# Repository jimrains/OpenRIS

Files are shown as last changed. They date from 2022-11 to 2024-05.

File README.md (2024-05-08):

# OpenRIS



Reconfigurable Intelligent Surface project for the WiDeS Group at USC / CSI Group at University of Glasgow. Please direct enquiries to james.rains@essex.ac.uk. 

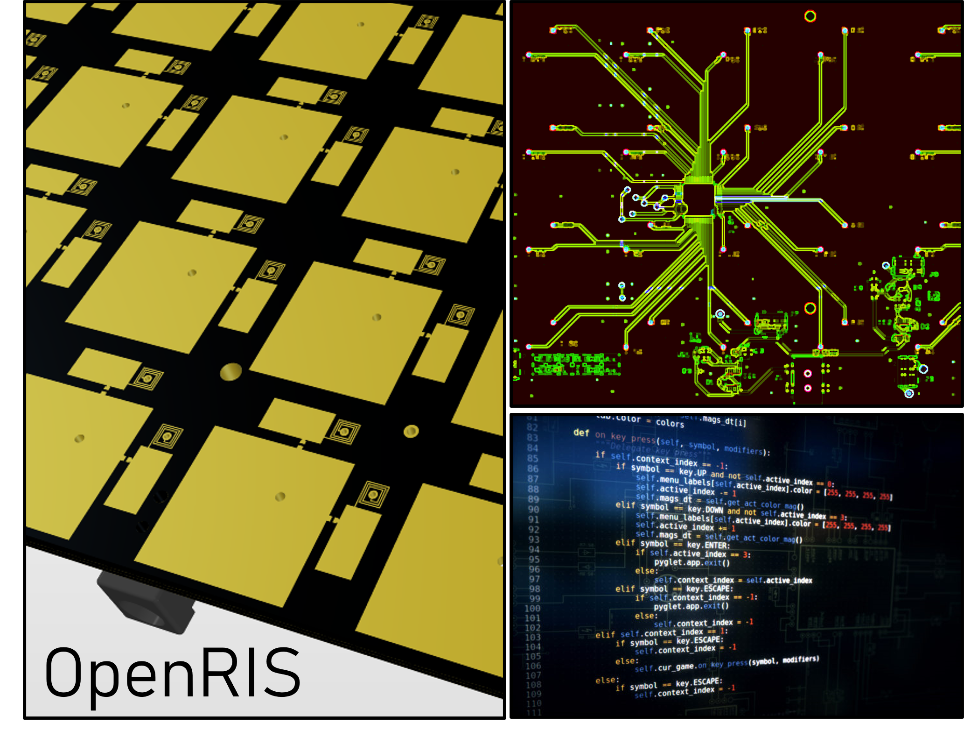
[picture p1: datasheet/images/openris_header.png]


# Documentation

- [Datasheet](https://github.com/jimrains/USCRIS/tree/main/datasheet) - general performance information
- [Control interface](https://github.com/jimrains/USCRIS/tree/main/control) - programming information
- [Hardware](https://github.com/jimrains/USCRIS/tree/main/hardware) - details of the digital hardware
- [Publications](https://github.com/jimrains/USCRIS/tree/main/publications) - papers on and involving the OpenRIS prototype
- [Measurements](https://github.com/jimrains/USCRIS/tree/main/measurements) - data on far-field pattern measurements and channel sounding

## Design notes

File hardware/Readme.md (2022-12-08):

# Hardware

This directory contains information regarding the RIS digital hardware. For information regarding the design of the metasurface, see [this paper](https://github.com/jimrains/USCRIS/blob/main/publications/1_bit_DP_EuCAP_2023_Conference-5.pdf).

## Metasurface

## Control circuit

The below diagram shows the digital circuit side of a RIS tile. Each tile consists of 16 high voltage shift registers, each with 32 digital outputs which can take on voltage levels of 0 and V2 volts for logic low and logic high, respectively. These shift registers are addressed by a Raspberry Pi 3B via a logic level shifter. A power distribution circuit transforms the voltage at the input jack into two manually tunable voltage levels.

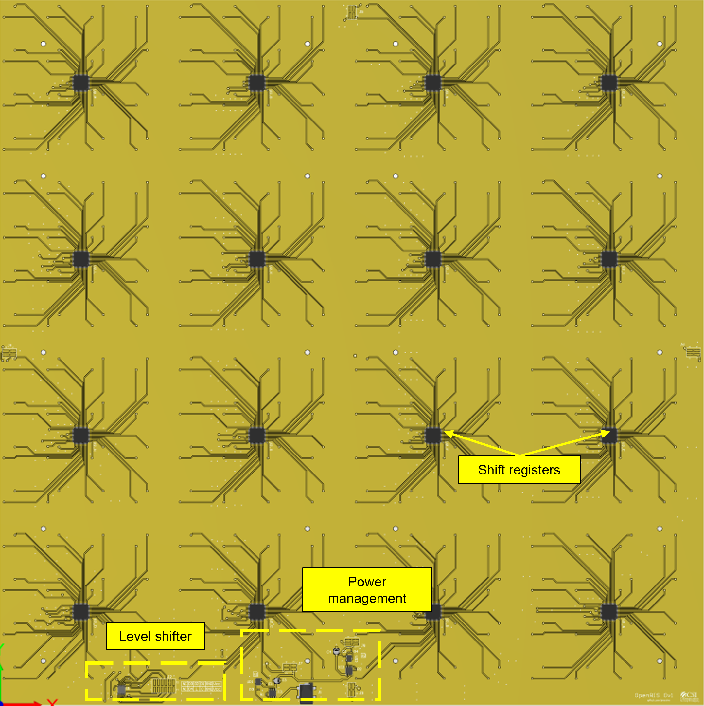
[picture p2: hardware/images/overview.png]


## Subcircuits

### Shift registers

There are a total of 512 individually controllable varactor diodes per tile, served by a network of shift registers. The control circuitry is centred around HV5308 shift registers. These are cascaded in groups of 4. Each shift register contains 32 digital outputs with logic levels 0 and V2 volts. A single shift register supports the 2 polarisations of 16 unit cells such that they may be individually addressed.

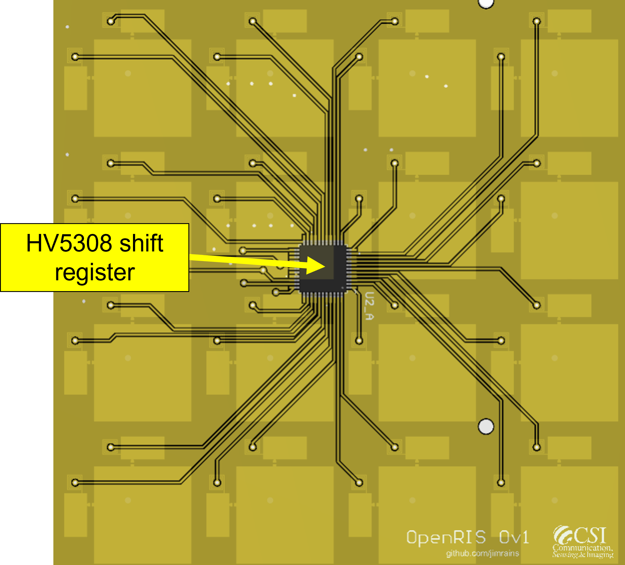
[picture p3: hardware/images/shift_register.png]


### Level shifter

To interface with the high voltage shift registers, the digital control signals from the Raspberry Pi need to be converted to a higher voltage. The Raspberry Pi GPIO pins provide a logical low and high of 0 V and 3.3 V, respectively. The HV5308 ICs have a recommended operating voltage of 8 - 12 V. We use the CD4504 shift register ICs for this logic voltage level shifting. A logic high of 3.3 V is converted into the shift register logic voltage, V2.

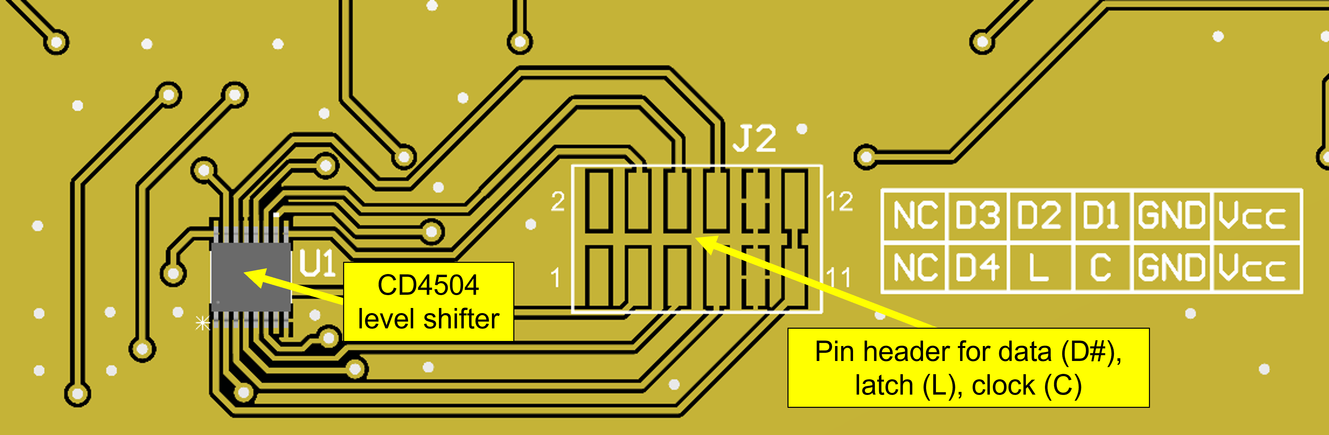
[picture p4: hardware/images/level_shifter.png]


The pinout for this can be found on the [datasheet](../datasheet) page and a print of the tile-side pinout can be seen in the above image.

### Power management

Voltage regulation is performed by two LN2954 ICs, providing V1 and V2. V1 is applied to the square patches of the RIS elements and V2 is used as the logic high level for the shift registers. These have been placed in series so that V2 is always greater than V1. This is to ensure that the varactor diodes are always reverse-biased.

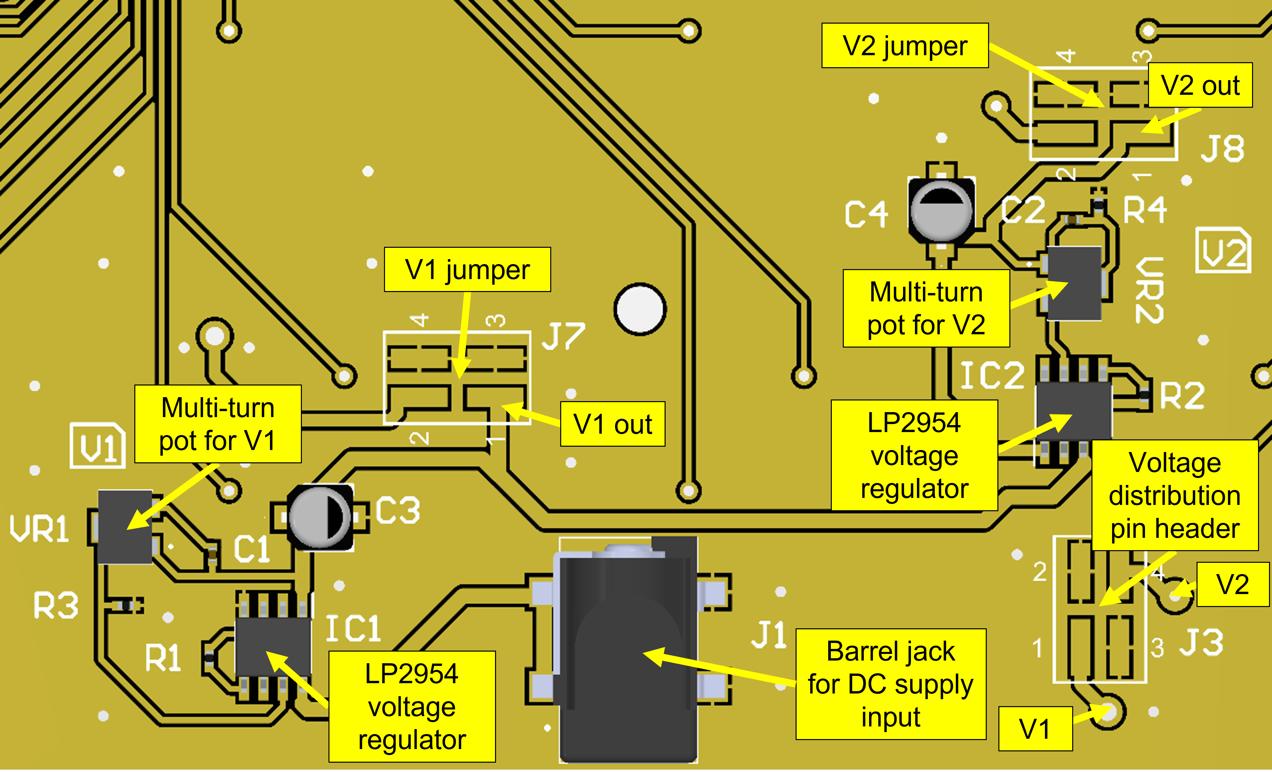
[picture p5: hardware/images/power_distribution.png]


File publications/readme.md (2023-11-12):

# Publications

We have published work on the initial design in EuCAP 2023 which can be found:
[Rains et al., Fully-Addressable Varactor-Based Reflecting Metasurface with Dual-Linear Polarisation for Low Power Reconfigurable Intelligent Surfaces, EuCAP 2023](https://ieeexplore.ieee.org/abstract/document/10133408)

Field trials in an outdoor urban macrocell were recently performed and the results will be published shortly. A draft of the paper can be found in this directory, titled RIS-Enhanced MIMO Channels in Urban Environments: Experimental Insights.

For similar work by the authors, see:
[Rains, Kazim, Tukmanov et al., High-Resolution Programmable Scattering for Wireless Coverage Enhancement: An Indoor Field Trial Campaign, IEEE Transactions on Antennas and Propagation, 2022](https://ieeexplore.ieee.org/abstract/document/9931620)

[Usman, Rains, Cui et al., Intelligent wireless walls for contactless in-home monitoring, Nature LSA, 2022](https://www.nature.com/articles/s41377-022-00906-5)

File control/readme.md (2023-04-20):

# Control

This directory contains all the information necessary to set up and interface with the RIS prototype. 

RIS configurations are sent over a WiFi link hosted on the Raspberry Pi 3B. A socket is established with MATLAB acting as the client, connecting to a server running on the Raspberry Pi. The server-side software is currently written in Python. Configurations sent via MATLAB are transformed into the correct format by the Python program on the Pi side. The Pi then sets the digital states of the GPIO pins to program the shift registers on the respective RIS tiles. 

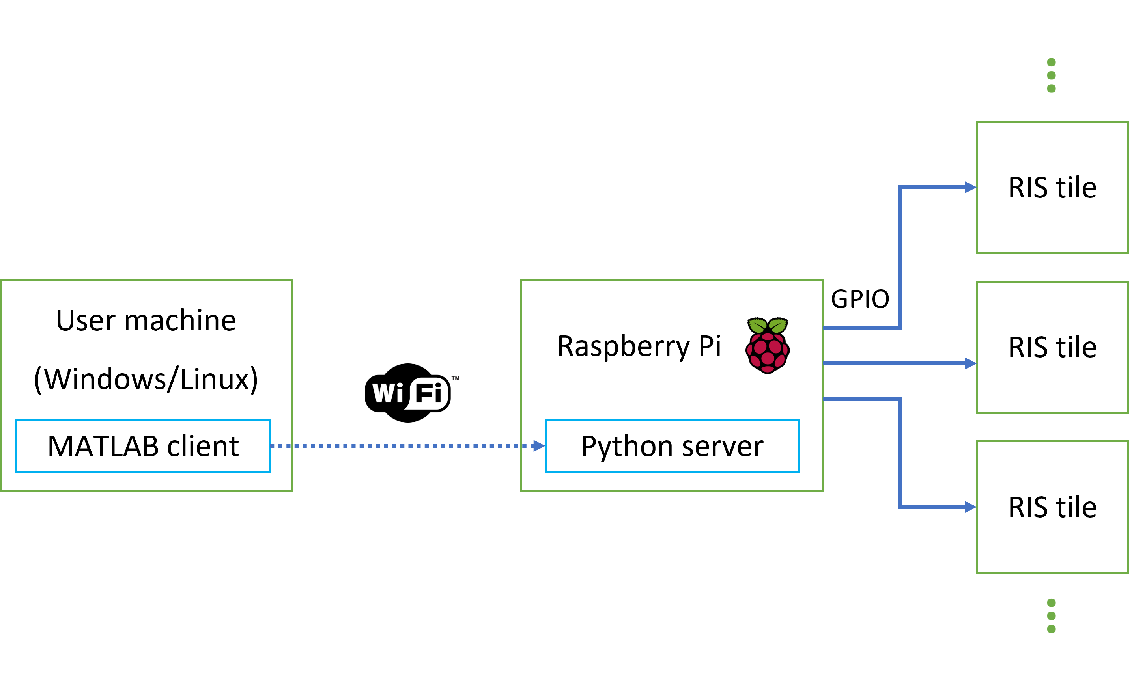
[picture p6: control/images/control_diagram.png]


## Ethernet Connection

It is possible to connect to the Raspberry Pi via an ethernet cable through a secure shell through the command:

**ssh pi@raspberrypi.local**

with the default password.

## WiFi Access Point

By default, the access point on the USC prototype is set up on boot, with an access point name **PiRS**. The password is the default and won't be posted here for obvious reasons (just ask James or others in the project). 

To set up an access point on the Raspberry Pi 3B from a fresh install, see the guide posted [here](https://learn.sparkfun.com/tutorials/setting-up-a-raspberry-pi-3-as-an-access-point/all). Note the static IP address you use in the __interfaces__ file.

As an alternative, you may set up a mobile hotspot on a PC and get the Pi to connect to you. To keep things simple, you may connect a monitor/keyboard/mouse to the Pi the first time you do this. 

## Socket Setup

The current procedure for setting up a socket for RIS control involves:

- Connect to the **PiRS** WiFi access point from the user machine
- Establish control of the Pi via SSH (i.e., via the command __ssh pi@192.168.4.1__). Use the default username and password.
- Run the program **python ~/control/socket-server-tiles.py**
- Note the port number **port_number** (this can be found in the **PORT** variable in the program)
- In MATLAB on the user machine, run the command **sock = tcpclient("192.168.4.1", port_number)** where **port_number** is an integer of the port number displayed when running the server

## MATLAB Interfacing

Configurations are sent over the socket in the form of a string of bits. Additionally, a tile number is sent so that the Pi knows which set of GPIO pins it should send the control signals over. 

## Pinouts

### Tile pinout

Each RIS tile requires 6 digital inputs alongside a DC voltage and a ground connection. The DC voltage should be the same level as the logic high. For the Raspberry Pi 3B, this will be 3.3 V. 

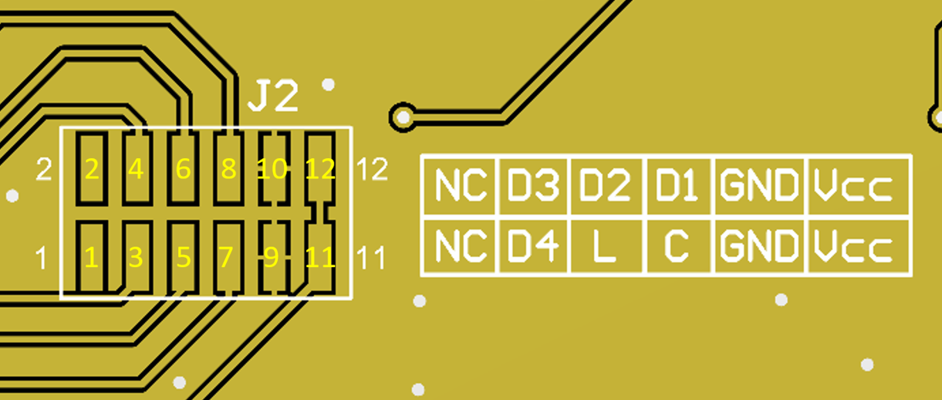
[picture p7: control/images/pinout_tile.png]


| Pin # | ID | Function | T1->Raspberry Pi | T2->Raspberry Pi |
|---|---|---|---|---|
| 1 | NC | Not connected | - | - |
| 2 | NC | Not connected | - | - |
| 3 | D4 | Data line 4 | 3->12 | 3->19 |
| 4 | D3 | Data line 3 | 4->10 | 4->18 |
| 5 | L | Latch (shifts out data to shift register outputs)  | 5->5 | 5->13 |
| 6 | D2 | Data line 2 | 6->8 | 6->16 |
| 7 | C | Clock (timing signal) | 7->3 | 7->11 |
| 8 | D1 | Data line 1 | 8->7 | 8->15 |
| 9 | GND  | DC ground | 9->6 | 9->14 |
| 10 | GND  | DC ground | - | - |
| 11 | Vcc  | DC voltage (3.3 V for Pi 3B) | 11->1 | 11->17 |
| 12 | Vcc  | DC voltage (3.3 V for Pi 3B) | - | - |

### Pi pinout



The pinout of the Raspberry Pi 3 will depend on the number of tiles that are utilised for a particular arrangement. This is governed by the **tile.h** file in this directory. The pin mapping for two tiles is shown in the two right-hand columns in the table above. The Pi GPIO pin numbers refer to the __board__ numbering scheme (i.e., the physical pin number). For more information on the Raspberry Pi GPIO interface, see [here](https://www.raspberrypi.com/documentation/computers/raspberry-pi.html#gpio-and-the-40-pin-header). 

## Pi Graphical User Interface

If for whatever reason you need to access the graphical user interface (GUI) of the Raspberry Pi, you can use a VNC viewer. One such program is RealVNC which can be found [here](https://www.realvnc.com/en/connect/download/vnc/). Follow the first two instructions in the **Socket Setup** section above, then:

- In the secure shell, run the command **vncserver**. Note down the IP address and the number following the colon.
- Open VNC Viewer or an equivalent program. Use the VNC server address **192.168.4.1:#** where **#** is the number obtained in the previous step (typically defaults to 1 if no other session is open).
- Enter the username and password of the Pi. This is set to default.

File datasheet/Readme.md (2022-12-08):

# Datasheet

This directory contains information on the device performance

## Overview of Operating Principles

A typical RIS deployment is shown in the image below. A receiver located within the user equipment (UE) is served by the base station (BS) via the reconfigurable intelligent surface (RIS), circumventing the highly-attenuating direct path between the BS and the UE.

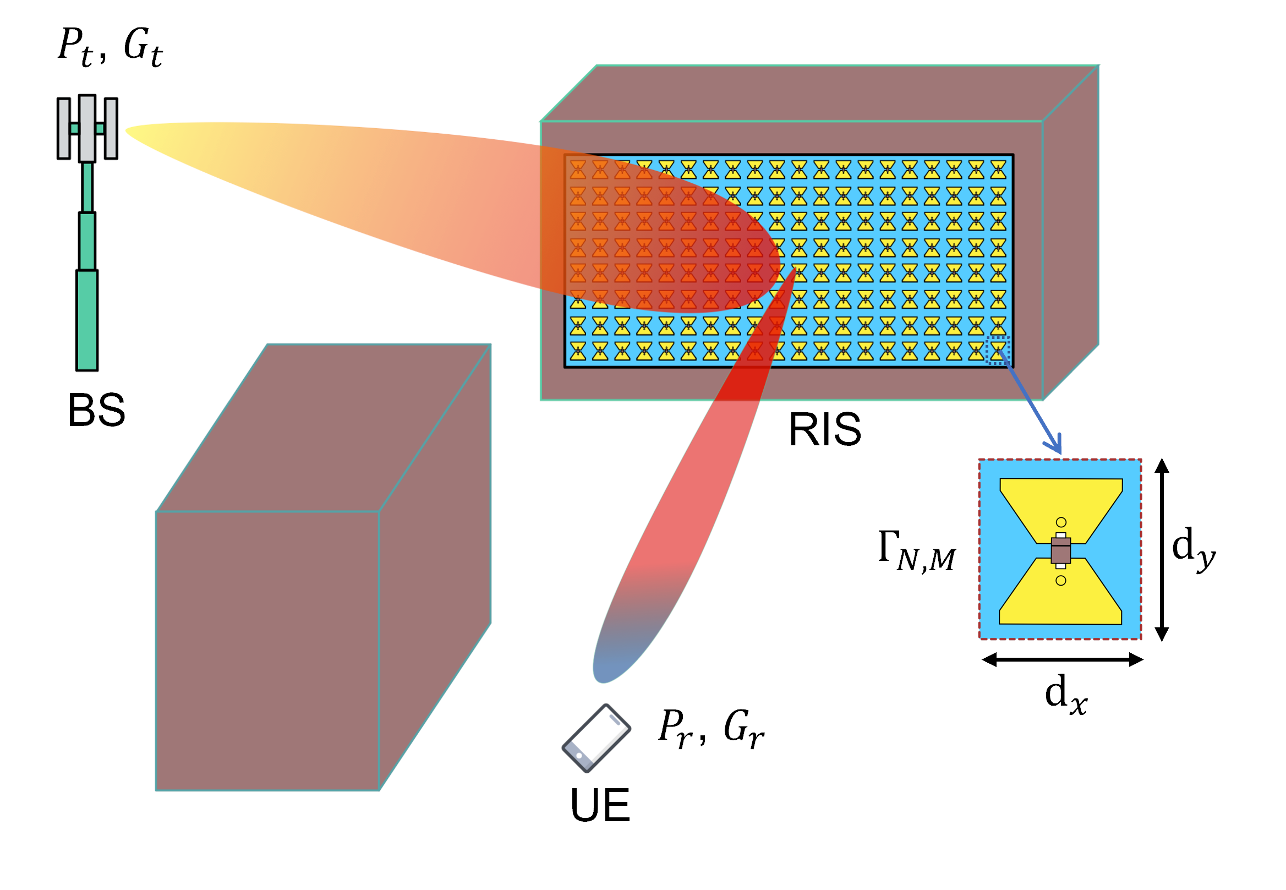
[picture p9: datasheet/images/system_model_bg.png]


If we consider a geometrical optics approximation, the below equation can be used to approximate the power $P_r$, received at an antenna with gain $G_r$, originating from reradiation from a RIS consisting of an arrangement of $MN$ elements. Each element is considered to have lateral dimensions $d_x$ and $d_y$ referring to the x and y axes, respectively. $\lambda$ is the wavelength at the frequency of interest. Taking the origin of the coordinate system at the center of the RIS, $r_{n,m}^t$ and $r_{n,m}^r$ are the distances between the transmitter and element (n,m) and the receiver and element (n,m), respectively. Any path between the transmitter and receiver is assumed to be neglible (thereby warranting the deployment of the RIS to mitigate this). The radiation patterns in reception and transmission are factored into the received power formulation through $F_{n,m}^{combine}$. 

$$ P_r = P_t\frac{G_tG_rd_xd_y\lambda^2}{64\pi^3}|\sum_{m=1-\frac{M}{2}}^{M/2}\sum_{n=1-\frac{N}{2}}^{N/2}\frac{\sqrt{F_{n,m}^{combine}}\ \Gamma_{n,m}}{r_{n,m}^tr_{n,m}^r}e^{(-j\frac{2\pi}{\lambda}(r_{n,m}^t+r_{n,m}^r))}|^2 $$

For a fixed RIS position, the controllability of the wireless channel is achieved through the tunability of $\Gamma_{n,m}$. For a given element geometry, $\Gamma_{n,m}$ determines the change in the phase and magnitude of an incident local electric field - this is observed on the re-radiated local electric field. As governed by the Huygen-Fresnel principle, we can craft the localised re-radiated electric field components such that they add constructively in a dominant direction, form a split beam, or any number of application-dependent forms. Elements are tuned by varying the reactance of the grid impedance associated with a given element. In the prototype in this archive, we have employed varactor diodes to provide this tunable impedance. The digital nature of the control circuitry limits us to 2 tuning states per polarisation per unit cell element. This does not pose a significant limitation on the beamforming performance of these devices.

### Examples

## Local Reflection Coefficients

To synthesise a desired RIS re-radiation response, we set the reflection coefficients $Γ_{n,m}$ associated with each unit cell. The RIS consists of many constituent elements, each of which can be tuned between 2 reflection coefficient values on each polarisation. This 2-state response is often referred to as a 1-bit response. The device provides a 1-bit reflection response at both linear polarisations. This 1-bit response needs to be tuned to the centre operating frequency. We can approximate what the local reflection coefficient for a given unit cell: 

- By placing the sample unit cell within a waveguide and measuring the S11, subject to some caveats (see [here](https://ieeexplore.ieee.org/abstract/document/5067833)), or
- By measuring the reflection response of a metasurface consisting of similar unit cell elements, each with the same bias conditions

We have opted for the second approach here since it requires no more equipment than that required for ascertaining the radiation patterns.

For information on usage of this local reflection coefficient data, skip to [here](https://github.com/jimrains/USCRIS/edit/main/datasheet/Readme.md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).

### Reflection coefficient measurement setup

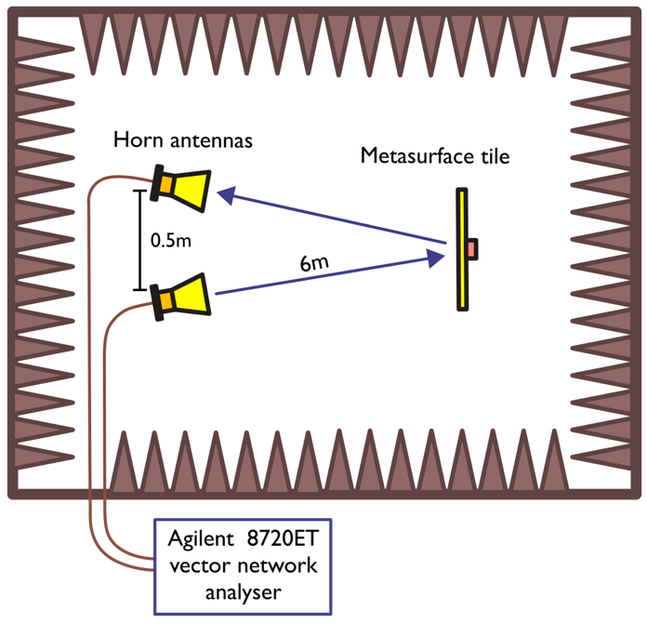
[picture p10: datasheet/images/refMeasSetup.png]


The two horn antennas, directed at the center of a single RIS tile, are positioned in the far-field of the sample. This distance should be approximately $r = 2D^2/\lambda$ where D is the lateral dimension and $\lambda$ is the shortest wavelength of interest. The antennas are spaced 0.5 m apart to avoid mutual coupling between them. The tile will reflect most of the incident power in the specular direction and this is what we exploit to ascertain the reflection coefficients. We assume that local reflection coefficients - that is, the complex coefficient determining the nature of the local electric field that is re-radiated from a given element on the surface - can be approximated by the global reflection behaviour of the surface. These reflection coefficients can be varied by changing the reverse-bias voltage of the varactor diodes in each unit cell. It is necessary to extract these values globally as it is difficult to measure the reflection response of any single unit cell.

### Calibration

In order to remove the contributions of the cables, horn antennas, and path loss from S21 response in the measurements, we first normalise to the reflection response of a homogenous metal plate. A copper plate is placed in contact with the tile face and the S21 is normalised. This results in the reference case of a "perfect" reflector. The reflection coefficients are then extracted by removing the copper plate and ascertaining the magnitude and phase responses for the varactor reverse bias voltage levels of interest.

### Local reflection response

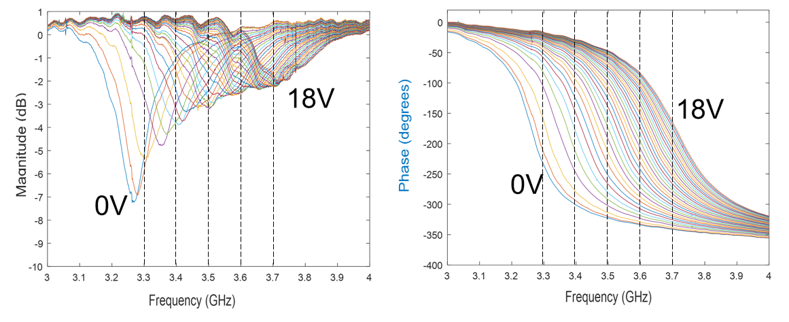
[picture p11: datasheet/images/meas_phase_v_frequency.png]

Γ magnitude and phase versus frequency

<br><br>

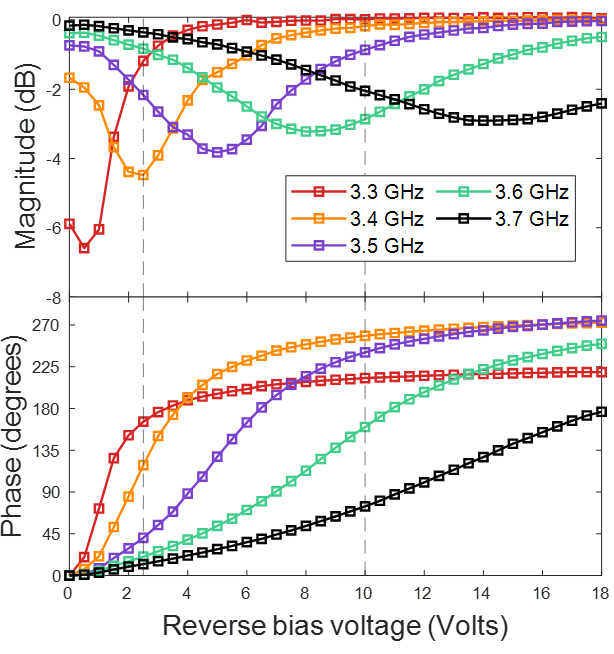
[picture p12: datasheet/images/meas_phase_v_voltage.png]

Γ magnitude and phase versus reverse-bias voltage

### Local reflection coefficients: how to use this data

The raw data for the local reflection responses is available in the measurements folder. 

## Radiation Patterns

For the **experiment setup** for extraction of the far-field patterns of a single tile, see [here](../measurements). Far-field to far-field radiation patterns have been extracted for 4 transmitter positions with incident angles, relative to broadside, of 0, 15, 30, and 45 degrees. Below is a representative example. The remaining curves and data can be found in the [measurements](../measurements) directory. The [numerical approximations]() are shown in blue, whilst the measured data points are displayed in red.

The measurement setup is depicted below and details can be found [here](../measurements).

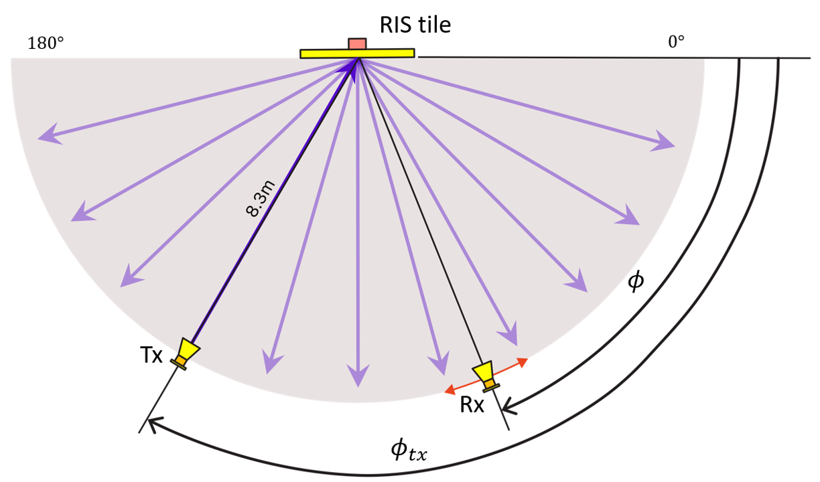
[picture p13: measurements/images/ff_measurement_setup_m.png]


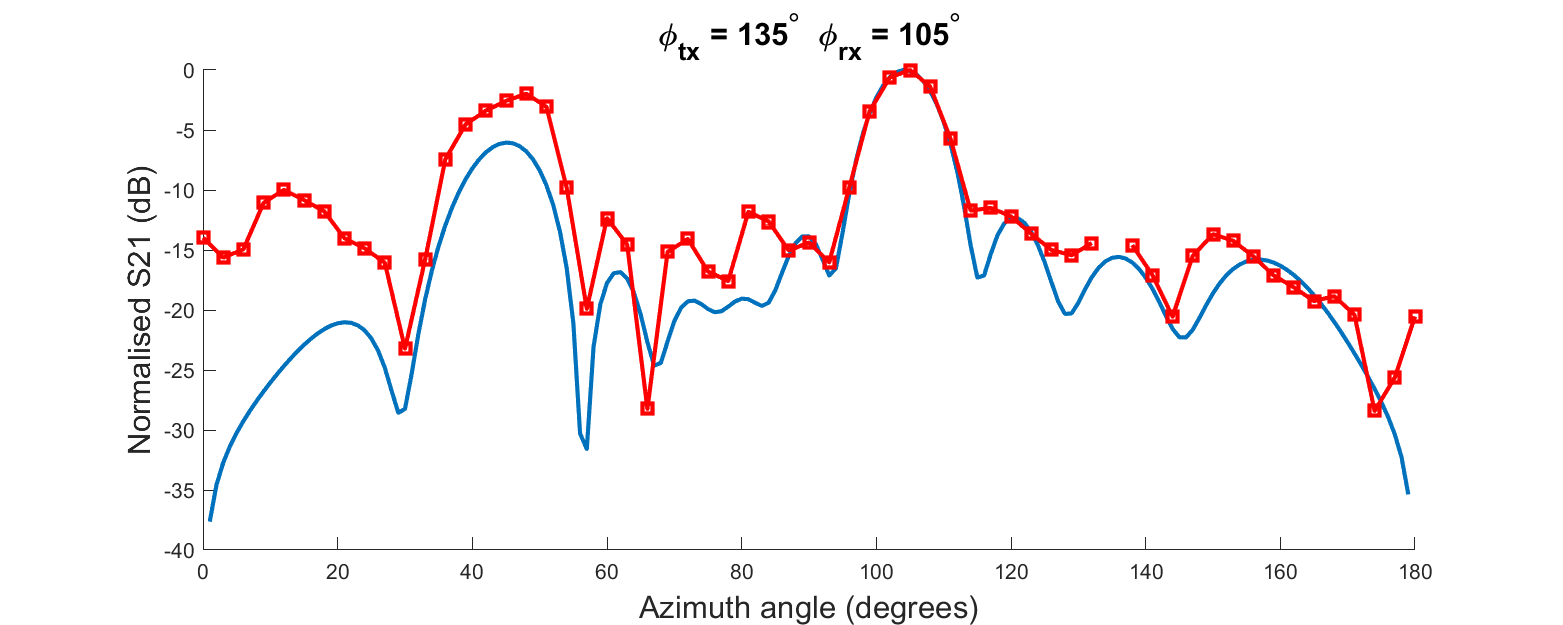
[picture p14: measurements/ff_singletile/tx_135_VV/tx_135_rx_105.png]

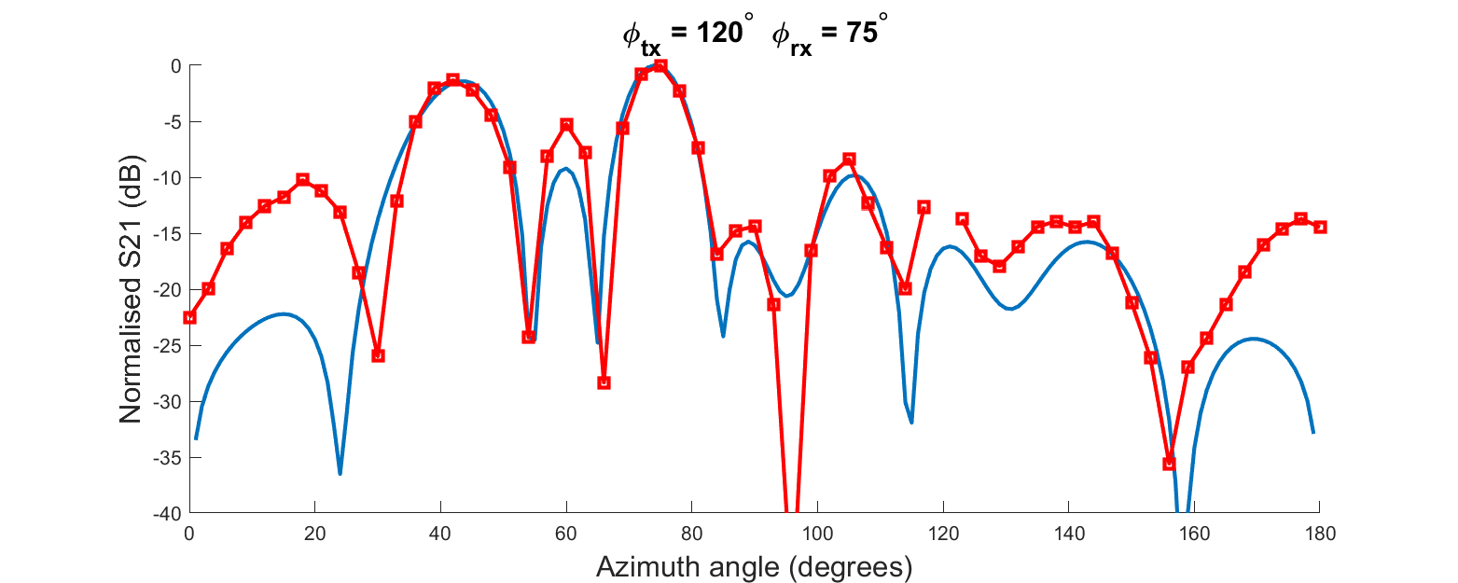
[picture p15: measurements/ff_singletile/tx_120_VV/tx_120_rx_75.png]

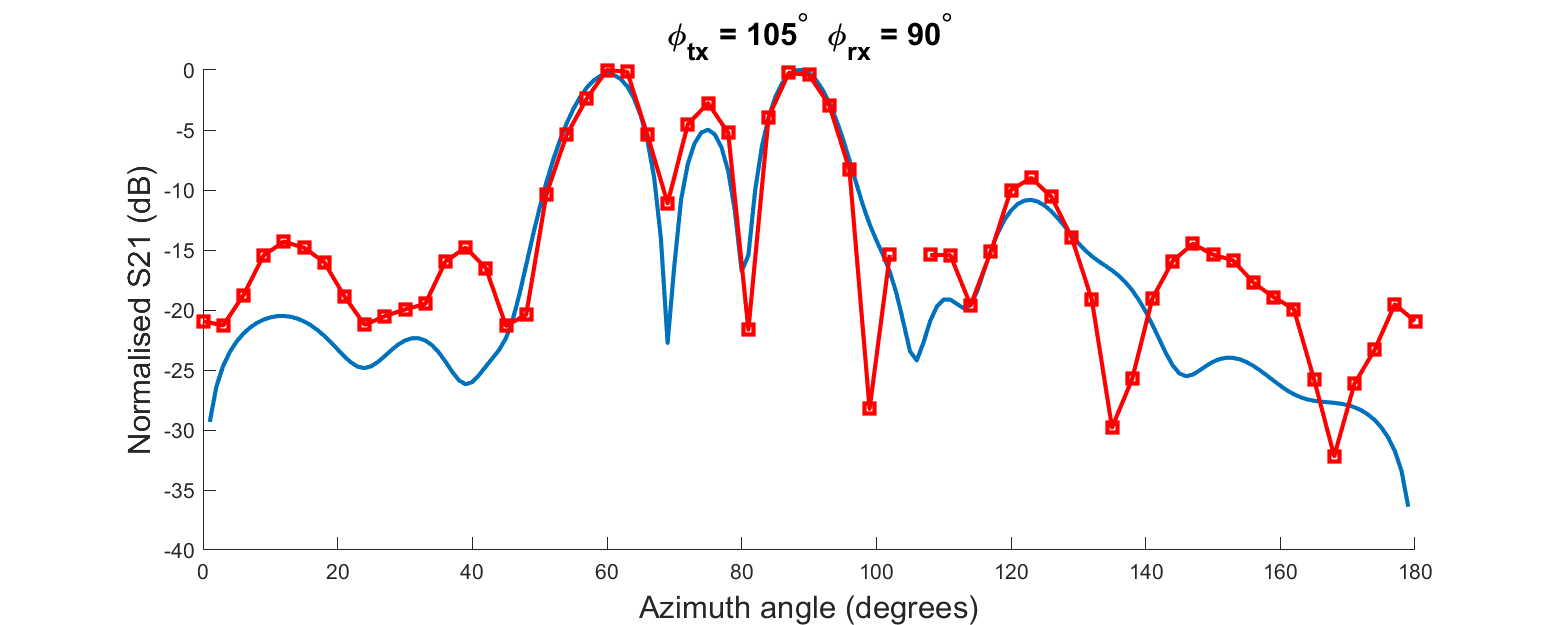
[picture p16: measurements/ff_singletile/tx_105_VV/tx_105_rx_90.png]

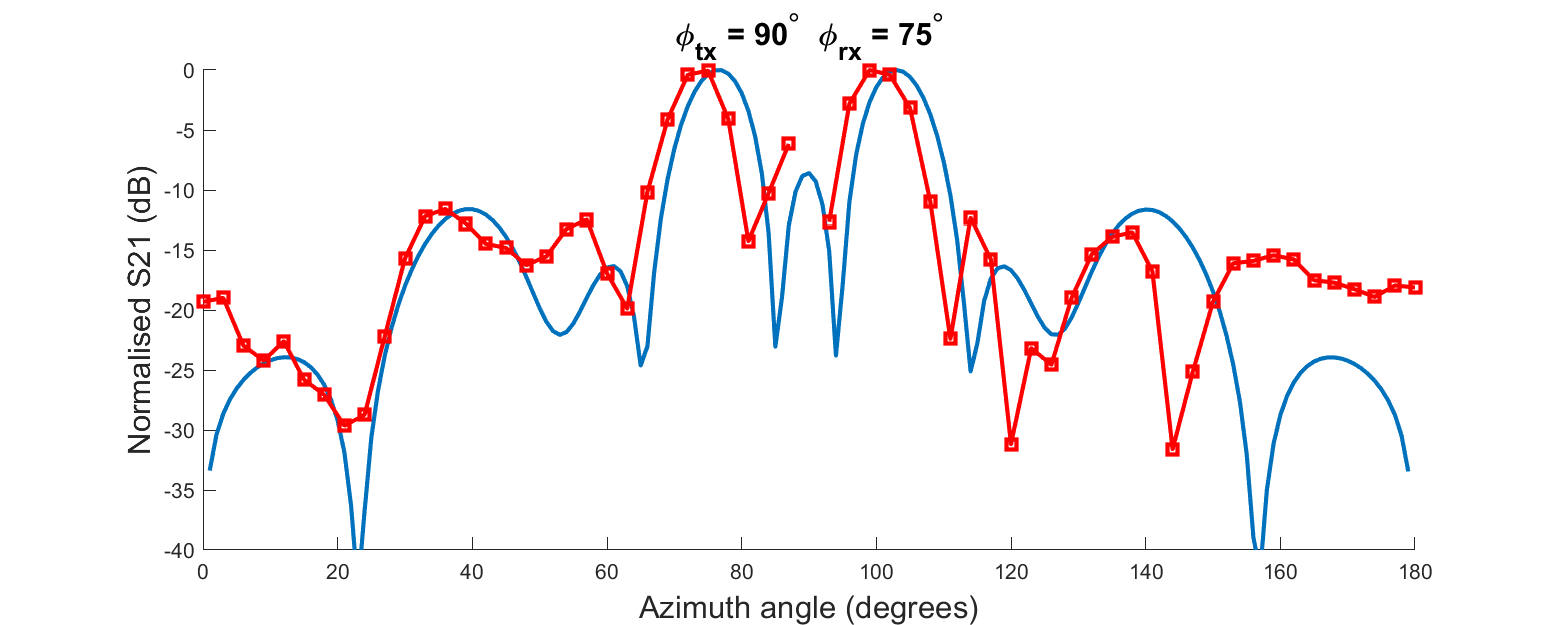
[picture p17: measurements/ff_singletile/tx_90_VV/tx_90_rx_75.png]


### Radiation patterns: how to use this data

The pattern measurements detailed here give a representative example of the beamforming capabilities of the device.

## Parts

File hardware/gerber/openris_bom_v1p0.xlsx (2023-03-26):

Comment | Description | Designator | Footprint | LibRef | Quantity
VJ0402A101GXBAC | Capacitor 100 pF 0402 | C1, C2 | CAPC1005X55N | VJ0402A101GXBAC | 2
TSM-102-01-L-DV-P-TR | 4 pin connector surface mount | J3, J4, J5, J6 | SAMTEC-A-TSM-102-02-L-DV | TSM-102-01-L-DV-P-TR | 4
SMV1408-040LF | Skyworks SMV1408-040LF varactor diode | D1_A, D1_B, D1_C, D1_D, D1_E, D1_F, D1_G, D1_H, D1_I, D1_J, D1_K, D1_L, D1_M, D1_N, D1_O, D1_P, D2_A, D2_B, D2_C, D2_D, D2_E, D2_F, D2_G, D2_H, D2_I, D2_J, D2_K, D2_L, D2_M, D2_N, D2_O, D2_P, D3_A, D3_B, D3_C, D3_D, D3_E, D3_F, D3_G, D3_H, D3_I, D3_J, D3_K, D3_L, D3_M, D3_N, D3_O, D3_P, D4_A, D4_B, D4_C, D4_D, D4_E, D4_F, D4_G, D4_H, D4_I, D4_J, D4_K, D4_L, D4_M, D4_N, D4_O, D4_P, D5_A, D5_B, D5_C, D5_D, D5_E, D5_F, D5_G, D5_H, D5_I, D5_J, D5_K, D5_L, D5_M, D5_N, D5_O, D5_P, D6_A, D6_B, D6_C, D6_D, D6_E, D6_F, D6_G, D6_H, D6_I, D6_J, D6_K, D6_L, D6_M, D6_N, D6_O, D6_P, D7_A, D7_B, D7_C, D7_D, D7_E, D7_F, D7_G, D7_H, D7_I, D7_J, D7_K, D7_L, D7_M, D7_N, D7_O, D7_P, D8_A, D8_B, D8_C, D8_D, D8_E, D8_F, D8_G, D8_H, D8_I, D8_J, D8_K, D8_L, D8_M, D8_N, D8_O, D8_P, D9_A, D9_B, D9_C, D9_D, D9_E, D9_F, D9_G, D9_H, D9_I, D9_J, D9_K, D9_L, D9_M, D9_N, D9_O, D9_P, D10_A, D10_B, D10_C, D10_D, D10_E, D10_F, D10_G, D10_H, D10_I, D10_J, D10_K, D10_L, D10_M, D10_N, D10_O, D10_P, D11_A, D11_B, D11_C, D11_D, D11_E, D11_F, D11_G, D11_H, D11_I, D11_J, D11_K, D11_L, D11_M, D11_N, D11_O, D11_P, D12_A, D12_B, D12_C, D12_D, D12_E, D12_F, D12_G, D12_H, D12_I, D12_J, D12_K, D12_L, D12_M, D12_N, D12_O, D12_P, D13_A, D13_B, D13_C, D13_D, D13_E, D13_F, D13_G, D13_H, D13_I, D13_J, D13_K, D13_L, D13_M, D13_N, D13_O, D13_P, D14_A, D14_B, D14_C, D14_D, D14_E, D14_F, D14_G, D14_H, D14_I, D14_J, D14_K, D14_L, D14_M, D14_N, D14_O, D14_P, D15_A, D15_B, D15_C, D15_D, D15_E, D15_F, D15_G, D15_H, D15_I, D15_J, D15_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 | SMV1408040LF | SMV1408-040LF | 512
SAMTEC-A-TSM-106-02-L-DVJ | 12 way two row SMD pin header connector | J2 | SAMTEC-A-TSM-106-02-L-DV | SAMTEC-A-TSM-106-02-L-DVJ | 1
PRT-12748 | SparkFun Accessories DC Barrel Power Jack Connector SMD | J1 | SPARKFUN_PRT-12748 | PRT-12748 | 1
LP2954IM_NOPB | Texas Instruments LP2954IM/NOPB | IC1, IC2 | SOIC127P600X175-8N | LP2954IM_NOPB | 2
HV5308PG-B-G-M919 | HV5308 high voltage shift registers with QFP44 package | U2_A, U2_B, U2_C, U2_D, U2_E, U2_F, U2_G, U2_H, U2_I, U2_J, U2_K, U2_L, U2_M, U2_N, U2_O, U2_P | QFP44_10x10MC_MCH | HV5308PG-B-G-M919 | 16
EEE-FC1H1R0R | Capacitor Polarised 1 uF | C3, C4 | EEE1AA220WR | EEE-FC1H1R0R | 2
CRCW0402100KFKEDHP | Resistor 100k 0402 package | R1, R2, R3, R4 | RESC1005X40N | CRCW0402100KFKEDHP | 4
CD4504BMPWREP | CD4504 hex level shifters | U1 | PW16 | CD4504BMPWREP | 1
3224W-1-205G | Variable Resistors Bourns 2M ohm | VR1, VR2 | 3224W1205G | 3224W-1-205G | 2

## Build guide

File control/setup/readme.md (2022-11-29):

# Setting up the Pi for use in the USCRIS

This directory contains information regarding the setup of the Raspberry Pi single-board computer for use in the USCRIS system. 

## Raspberry Pi

### Access Point

### GPIO Interfacing

### Additional Notes

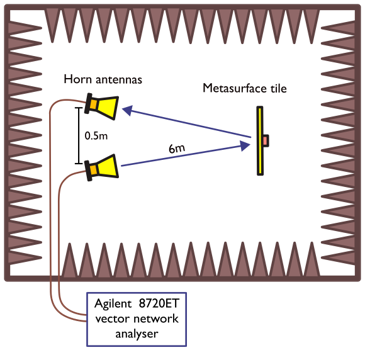
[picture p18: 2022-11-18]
datasheet/images/refMeasSetup.jpg

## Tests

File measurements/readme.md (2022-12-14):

# Measurements

This directory contains information from measurements involving the RIS. For general performance, see the [datasheet](../datasheet) directory.

## Far-field pattern measurements for a single RIS tile

Far-field to far-field radiation pattern measurements have been ascertained for a set of incident angles. These measurements were taken outdoors due to anechoic chamber space limitations. The setup for the measurements is depicted below. After two-port calibration of a Keysight PNA vector network analyser, the transmitter (Tx) and receiver (Rx) horn antennas were placed on a semicircle at a distance of 8.3 m from a single metasurface tile. All heights to the antenna centres were 1.5 m. The horn antennas were directed to the centre of the tile by use of a laser pointer and level. 



During each stage of the measurements, the Tx antenna remained static whilst the Rx antenna was placed at 3 degree intervals along a semicircle. At each Rx location, 11 configurations of the RIS were iterated through. This allowed us to extract 11 far-field patterns at each Rx position. These configurations were selected to maximise power in 11 different directions (15 to 165 degrees in 15 degree steps).

Below is a selection of radiation pattern measurements for a single tile. The x-axis, $\phi$, corresponds to navigation of the circumference of the semicircle highlighted in gray in the above diagram. For the full set of measurements, see the directories [here](./ff_singletile).


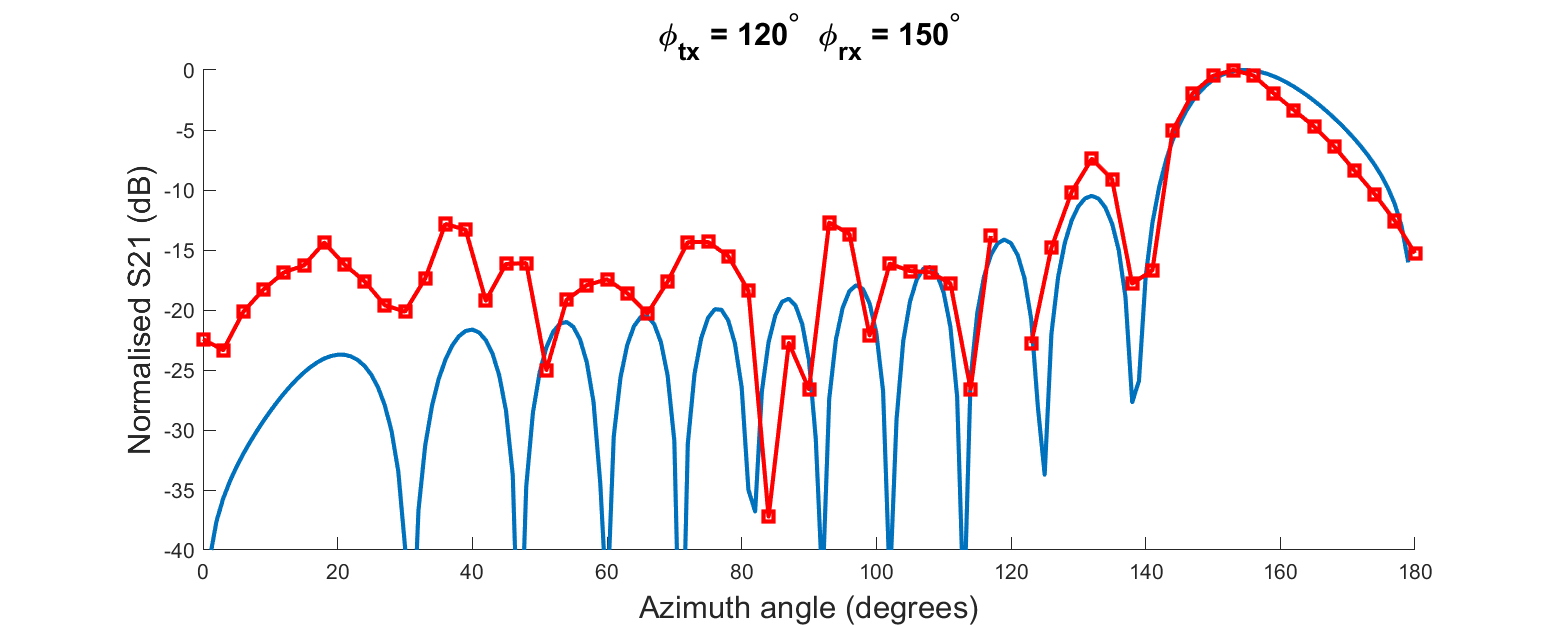
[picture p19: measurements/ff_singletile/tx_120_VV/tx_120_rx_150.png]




## Further information on outdoor far-field measurements

### Configuration selection

The RIS configurations were selected to maximise received power at a set of angles in the azimuthal plane relative to the RIS. For each incidence angle, dependent on the Tx position, 11 configurations were tested such that azimuth angles of $15^\circ$ to $165^\circ$ in $15^\circ$ steps. These configurations were generated through a simple algorithm that relies on a geometrical optics approximation given below.

If we consider a geometrical optics approximation, the below equation can be used to approximate the power $P_r$, received at an antenna with gain $G_r$, originating from reradiation from a RIS consisting of an arrangement of $MN$ elements. Each element is considered to have lateral dimensions $d_x$ and $d_y$ referring to the x and y axes, respectively. $\lambda$ is the wavelength at the frequency of interest. Taking the origin of the coordinate system at the center of the RIS, $r_{n,m}^t$ and $r_{n,m}^r$ are the distances between the transmitter and element (n,m) and the receiver and element (n,m), respectively. Any path between the transmitter and receiver is assumed to be neglible (thereby warranting the deployment of the RIS to mitigate this). The radiation patterns in reception and transmission are factored into the received power formulation through $F_{n,m}^{combine}$. 

$$ P_r = P_t\frac{G_tG_rd_xd_y\lambda^2}{64\pi^3}|\sum_{m=1-\frac{M}{2}}^{M/2}\sum_{n=1-\frac{N}{2}}^{N/2}\frac{\sqrt{F_{n,m}^{combine}}\ \Gamma_{n,m}}{r_{n,m}^tr_{n,m}^r}e^{(-j\frac{2\pi}{\lambda}(r_{n,m}^t+r_{n,m}^r))}|^2 $$

For a fixed RIS position, the controllability of the wireless channel is achieved through the tunability of $\Gamma_{n,m}$. For a given element geometry, $\Gamma_{n,m}$ determines the change in the phase and magnitude of an incident local electric field - this is observed on the re-radiated local electric field. Details on the formulation of this received power model can be found in [this paper](https://doi.org/10.1109/TAP.2022.3149660). 

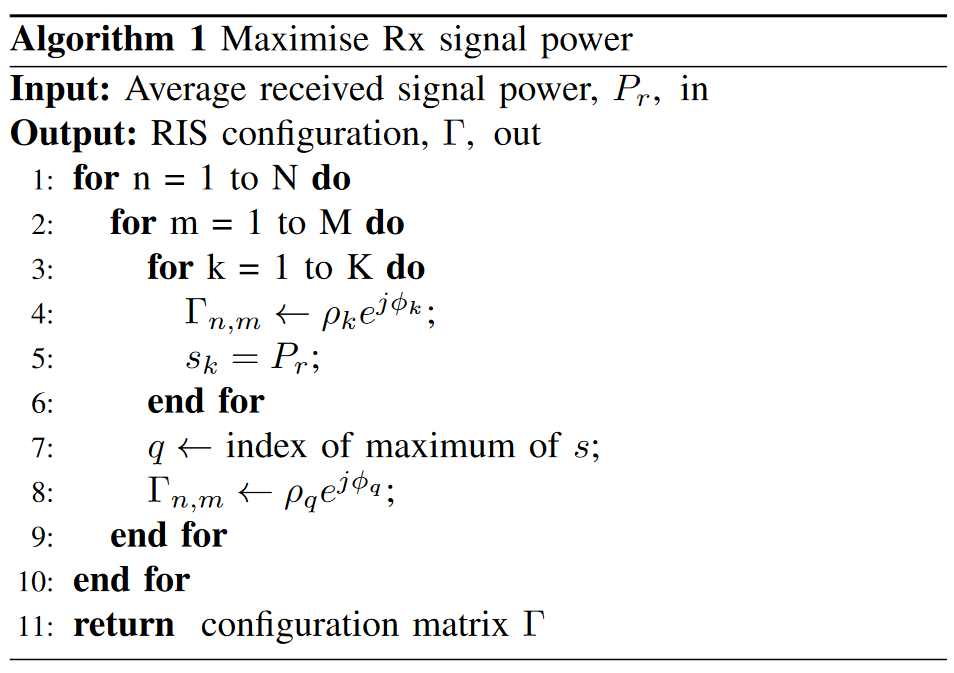
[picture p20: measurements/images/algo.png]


#### Example

See the program **calc_ris_pr.m** in the **ff_numerical_model** directory. By default, the below plots are generated. Configurations and associated far-field radiation patterns are shown in the first figure. These are power samples taken on a radius of 8.3 m (the same distance used in the measurements). The transmitter is located at 8.3 m at $120^\circ$. 

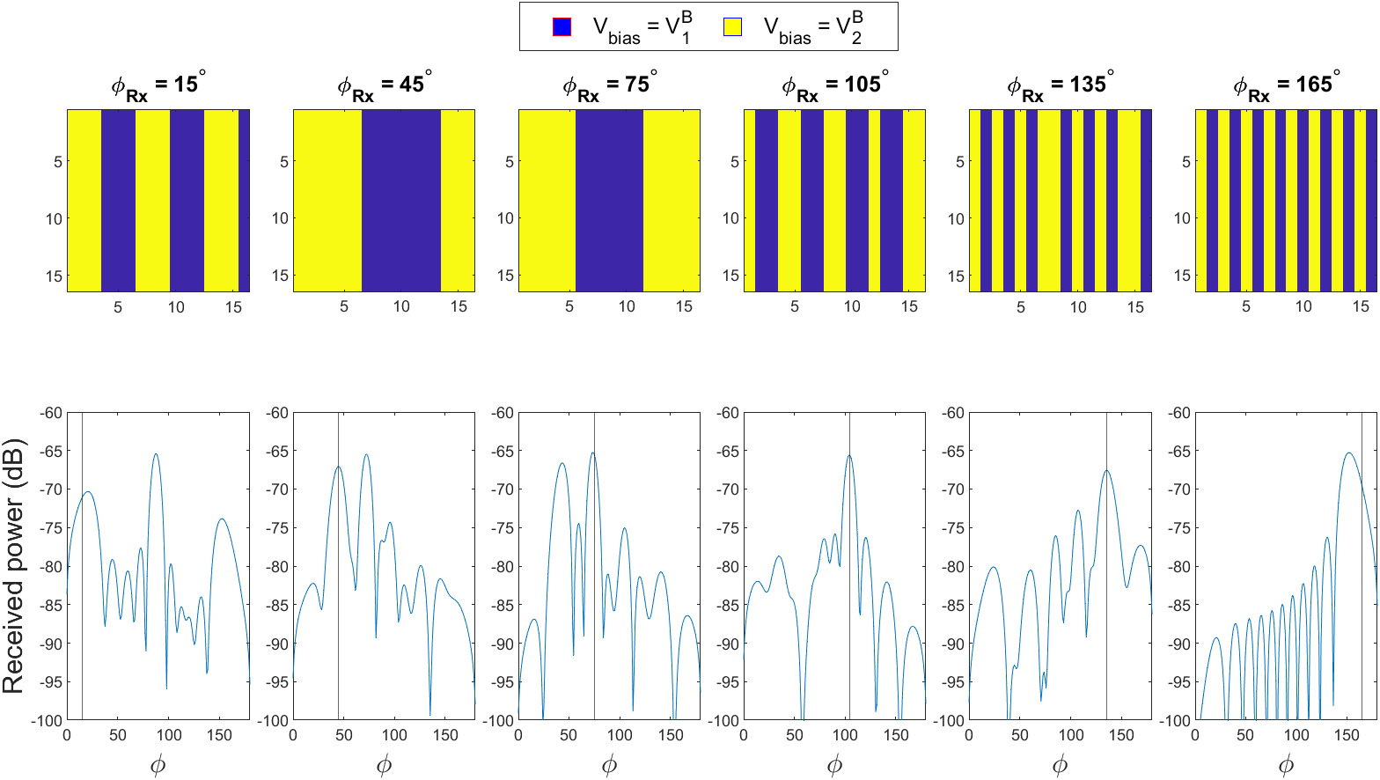
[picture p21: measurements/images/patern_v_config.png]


The second figure (below) shows received power versus position in the half-plane to the right-hand side of the RIS for 6 different RIS configurations. 

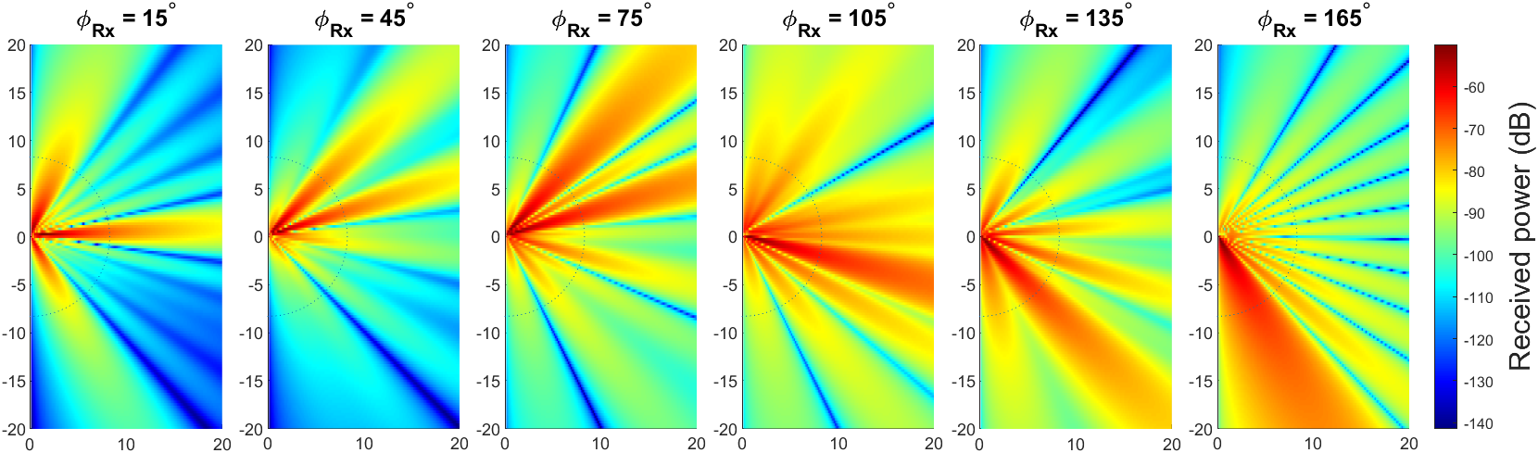
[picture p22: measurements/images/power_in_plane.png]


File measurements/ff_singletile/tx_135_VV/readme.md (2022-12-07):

# Far field patterns for Tx at 135 degrees VV polarisation

Parameters: V1=10V, V2=2.5V, f=3.58 GHz

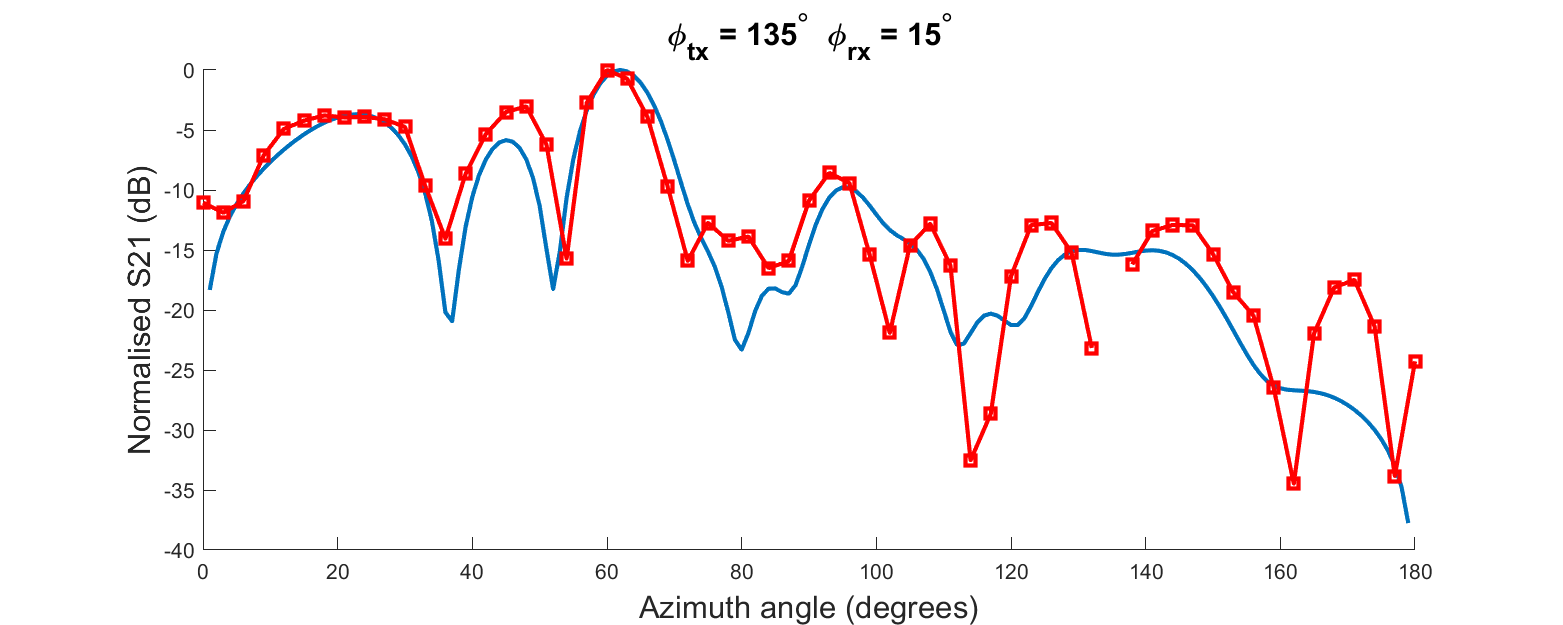
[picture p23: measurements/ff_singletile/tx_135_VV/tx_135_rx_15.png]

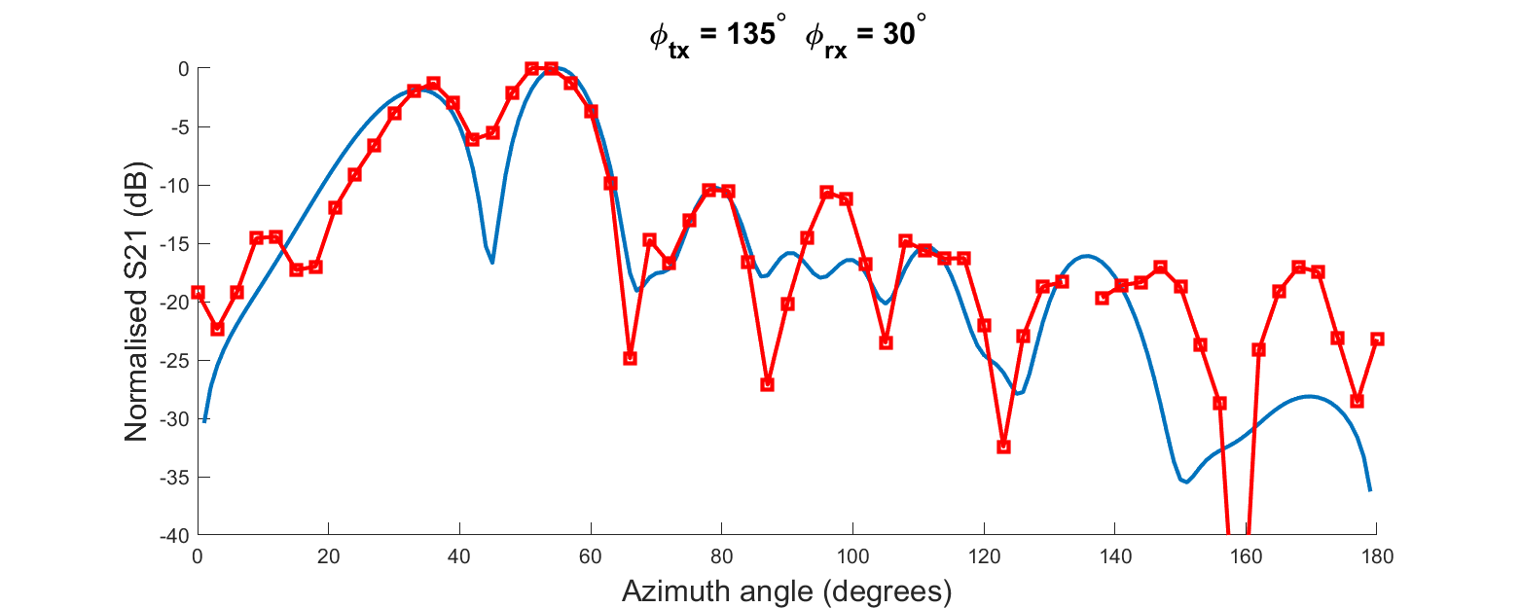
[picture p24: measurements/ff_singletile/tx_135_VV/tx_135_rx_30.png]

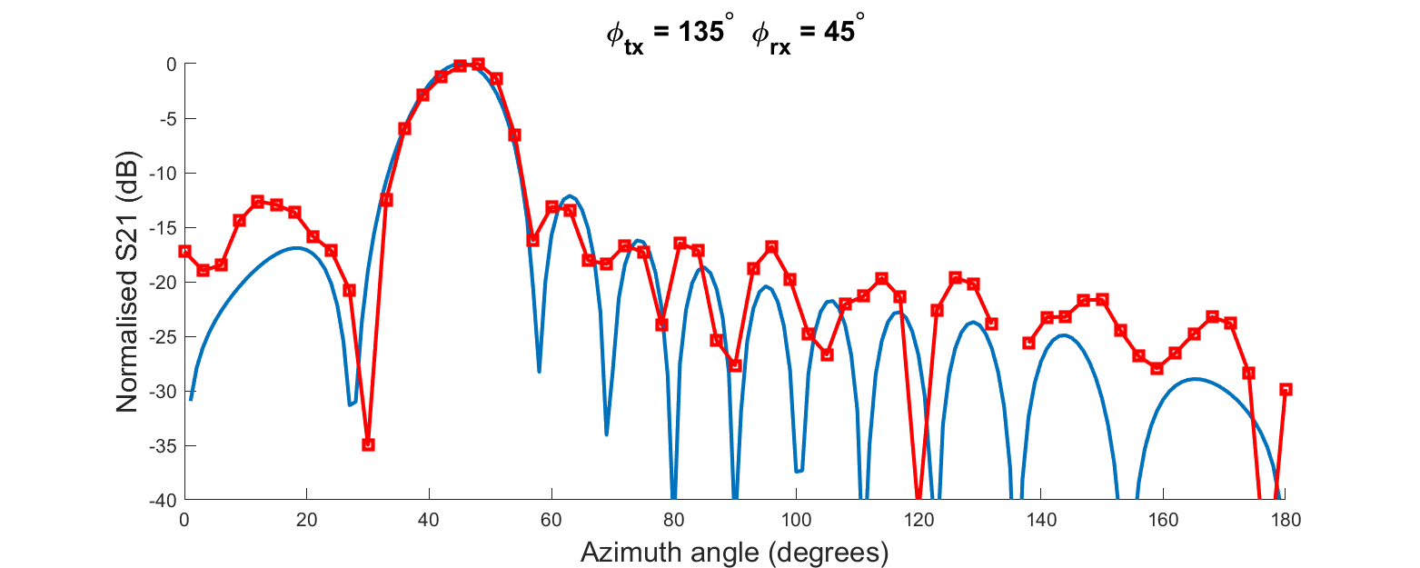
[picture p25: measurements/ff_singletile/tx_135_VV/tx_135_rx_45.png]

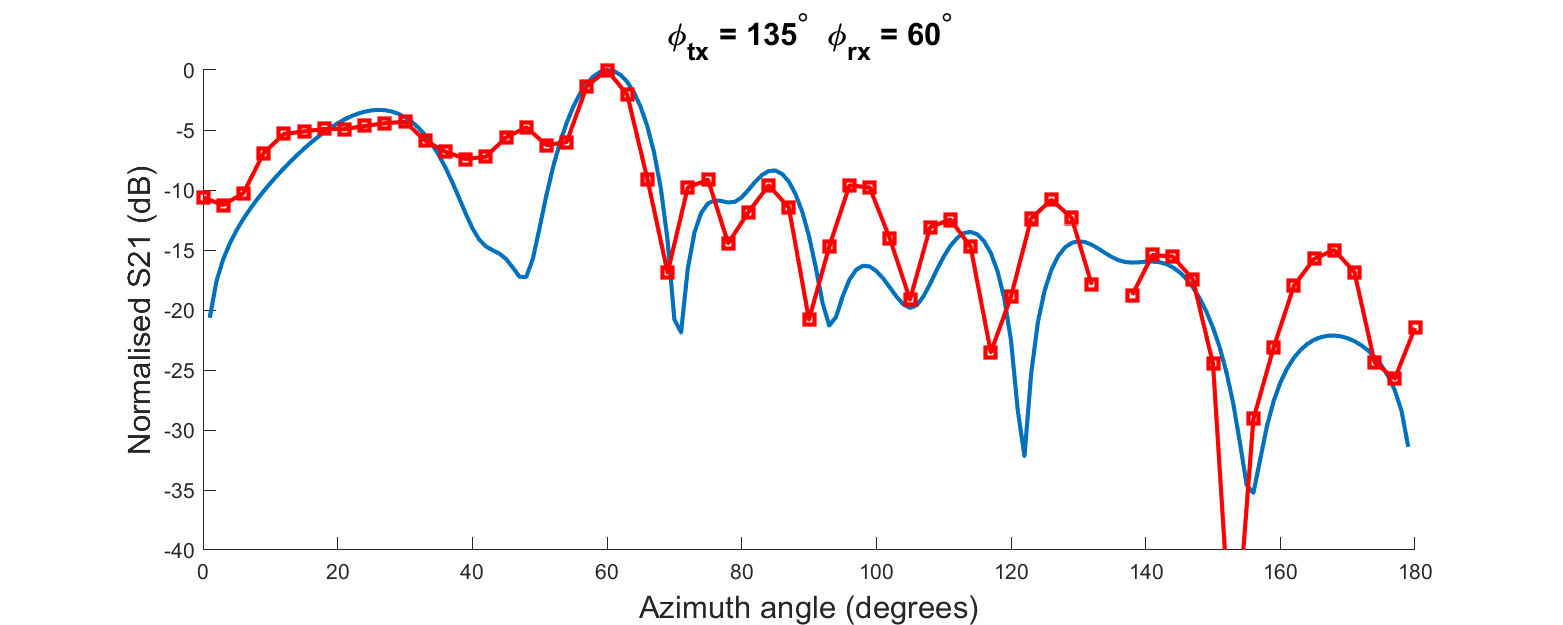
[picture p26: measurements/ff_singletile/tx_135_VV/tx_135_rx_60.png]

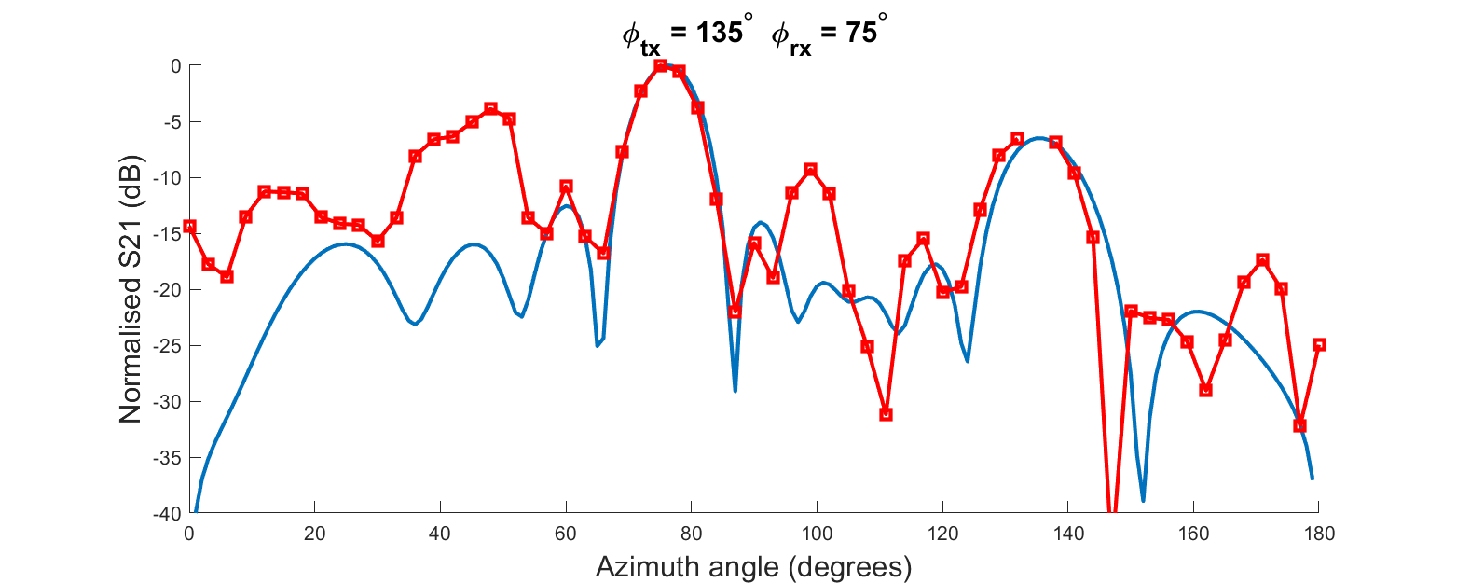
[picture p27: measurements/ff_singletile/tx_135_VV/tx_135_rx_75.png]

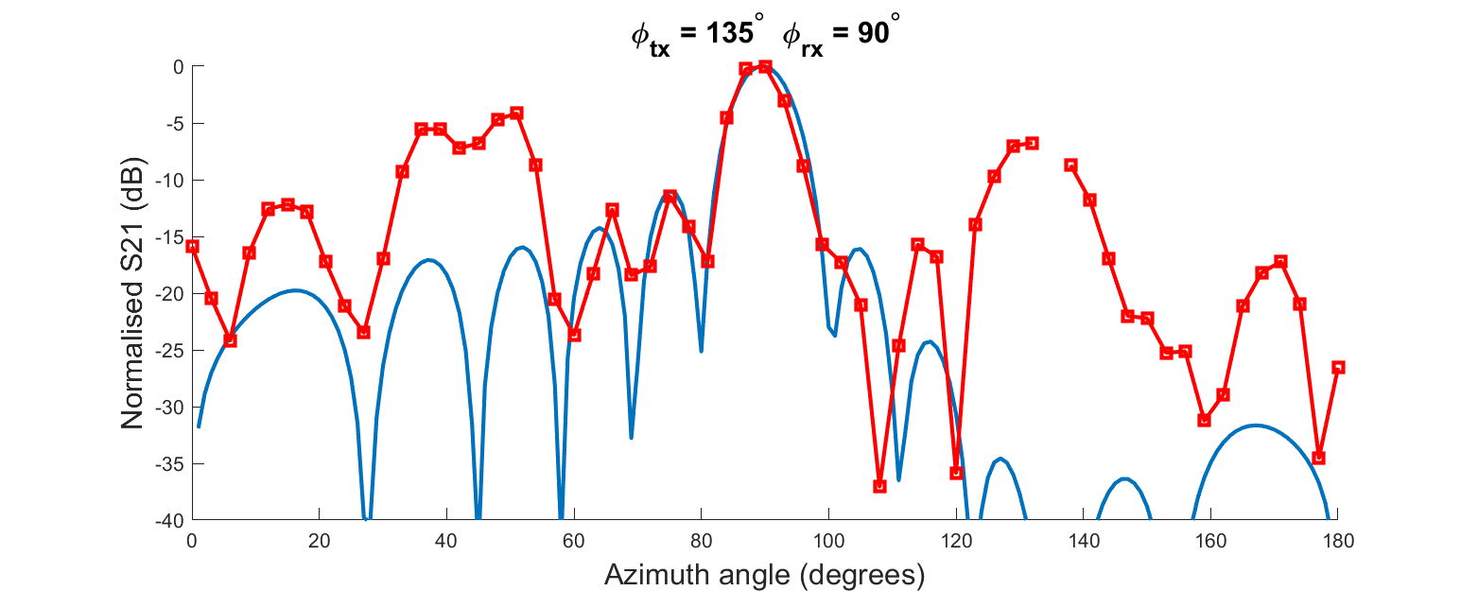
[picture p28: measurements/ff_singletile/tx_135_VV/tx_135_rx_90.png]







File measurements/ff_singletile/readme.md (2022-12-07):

# Far-field measurements for a single RIS tile

## Usage

This archive contains CSV data extracted from 61 positions on a semi-circle (0 to 180 degrees with 3 degree steps) at a distance of 8.3 m from a single RIS tile for various transmitter positions. The directories are in the format **tx_\<Tx angle\>_\<Polarisation of Tx\>\<Polarisation of Rx\>**. For example, __tx_120_VV__ contains data for the 61 positions with the transmitter located at an angle of 120 degrees and both Tx and Rx antennas vertically-polarised. Within each Tx position directory are directories of the format **rx_\<Rx angle\>**. These each contain 11 CSV files, each file corresponding to a single RIS configuration.

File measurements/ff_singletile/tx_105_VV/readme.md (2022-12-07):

# Far field patterns for Tx at 105 degrees VV polarisation













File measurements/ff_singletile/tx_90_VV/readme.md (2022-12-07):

# Far field patterns for Tx at 90 degrees VV polarisation













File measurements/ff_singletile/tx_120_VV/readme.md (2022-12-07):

# Far field patterns for Tx at 120 degrees VV polarisation













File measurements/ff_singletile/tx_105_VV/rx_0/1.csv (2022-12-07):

!CSV A.01.01
!Keysight Technologies | N5247A | US56070710 | A.10.64.09
!Date: Saturday | November 19 | 2022 23:55:42
!Source: Standard
BEGIN CH1_DATA
Freq(Hz) | S33(DB) | S33(DEG) | S34(DB) | S34(DEG) | S43(DB) | S43(DEG) | S44(DB) | S44(DEG)
3000000000 | -10.213813 | 174.14323 | -63.922905 | -96.373108 | -63.252945 | -101.17681 | -18.250628 | -165.93039
3005000000 | -15.076864 | 64.008644 | -63.103897 | 178.98141 | -62.883842 | 178.0107 | -17.484348 | -159.32495
3010000000 | -10.869102 | 103.05827 | -60.923378 | 89.686699 | -60.87693 | 88.336731 | -15.488135 | -172.73827
3015000000 | -9.138484 | 166.35677 | -59.422626 | 8.0689096 | -59.557205 | 13.22548 | -15.971396 | -159.127
3020000000 | -12.562459 | 24.946178 | -58.609676 | -81.074036 | -58.988792 | -81.157112 | -16.444698 | 179.19324
3025000000 | -6.3714566 | 130.38718 | -58.412498 | -164.12215 | -58.620205 | -164.25378 | -14.709204 | -165.22307
3030000000 | -27.777391 | 143.80855 | -58.276581 | 100.05132 | -58.299965 | 101.45398 | -18.610945 | 173.15152
3035000000 | -11.099607 | 54.7495 | -58.437111 | 8.9035244 | -57.782524 | 7.1179767 | -14.152808 | -176.71092
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

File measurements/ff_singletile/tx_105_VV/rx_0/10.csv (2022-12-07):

!CSV A.01.01
!Keysight Technologies | N5247A | US56070710 | A.10.64.09
!Date: Saturday | November 19 | 2022 23:56:24
!Source: Standard
BEGIN CH1_DATA
Freq(Hz) | S33(DB) | S33(DEG) | S34(DB) | S34(DEG) | S43(DB) | S43(DEG) | S44(DB) | S44(DEG)
3000000000 | -10.27859 | 172.93082 | -63.453171 | -97.055061 | -63.772259 | -101.30058 | -18.290028 | -162.2634
3005000000 | -16.142025 | 65.070641 | -62.832165 | -177.09677 | -63.175735 | -178.92154 | -17.344505 | -156.36946
3010000000 | -10.736187 | 106.48265 | -60.340084 | 89.245949 | -61.001469 | 93.651611 | -15.617342 | -169.37398
3015000000 | -9.4034243 | 167.84628 | -59.781925 | 11.209691 | -59.533184 | 9.8899107 | -15.907907 | -156.9397
3020000000 | -13.503492 | 27.874775 | -58.984325 | -79.838181 | -58.951271 | -80.765549 | -16.53307 | -177.04584
3025000000 | -6.5072079 | 130.92766 | -58.615063 | -162.89693 | -58.865452 | -161.3582 | -14.665552 | -163.10556
3030000000 | -26.353233 | 160.3896 | -58.644161 | 103.06964 | -58.824047 | 101.24252 | -18.69869 | 177.1337
3035000000 | -11.34207 | 58.972282 | -58.11385 | 11.366179 | -58.38826 | 9.1187572 | -14.076978 | -174.16908
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

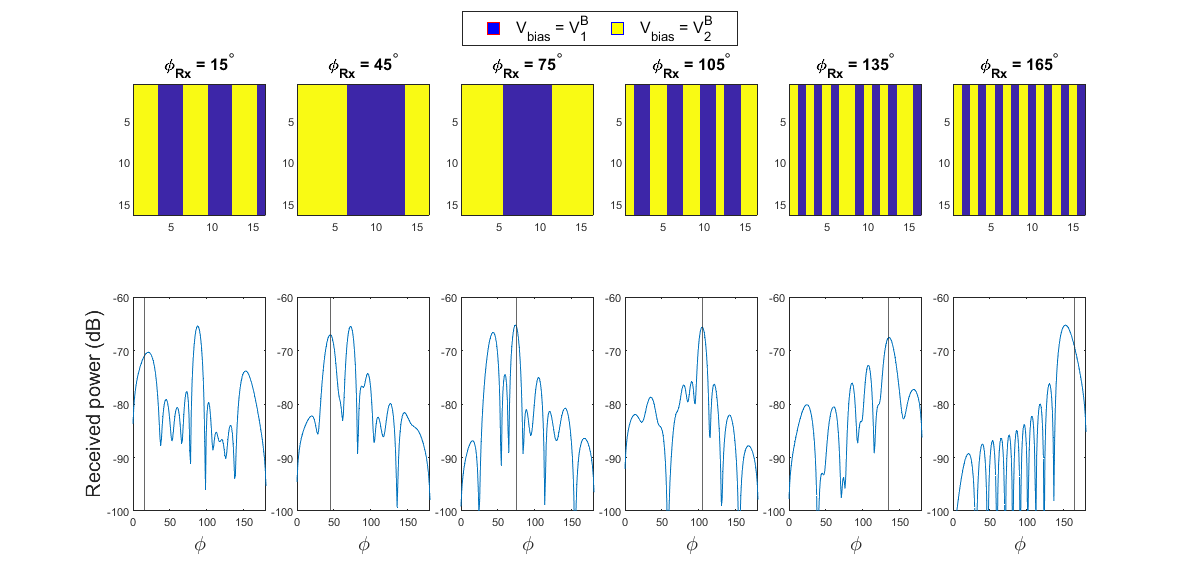
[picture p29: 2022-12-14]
measurements/images/configs_ffpatterns.png

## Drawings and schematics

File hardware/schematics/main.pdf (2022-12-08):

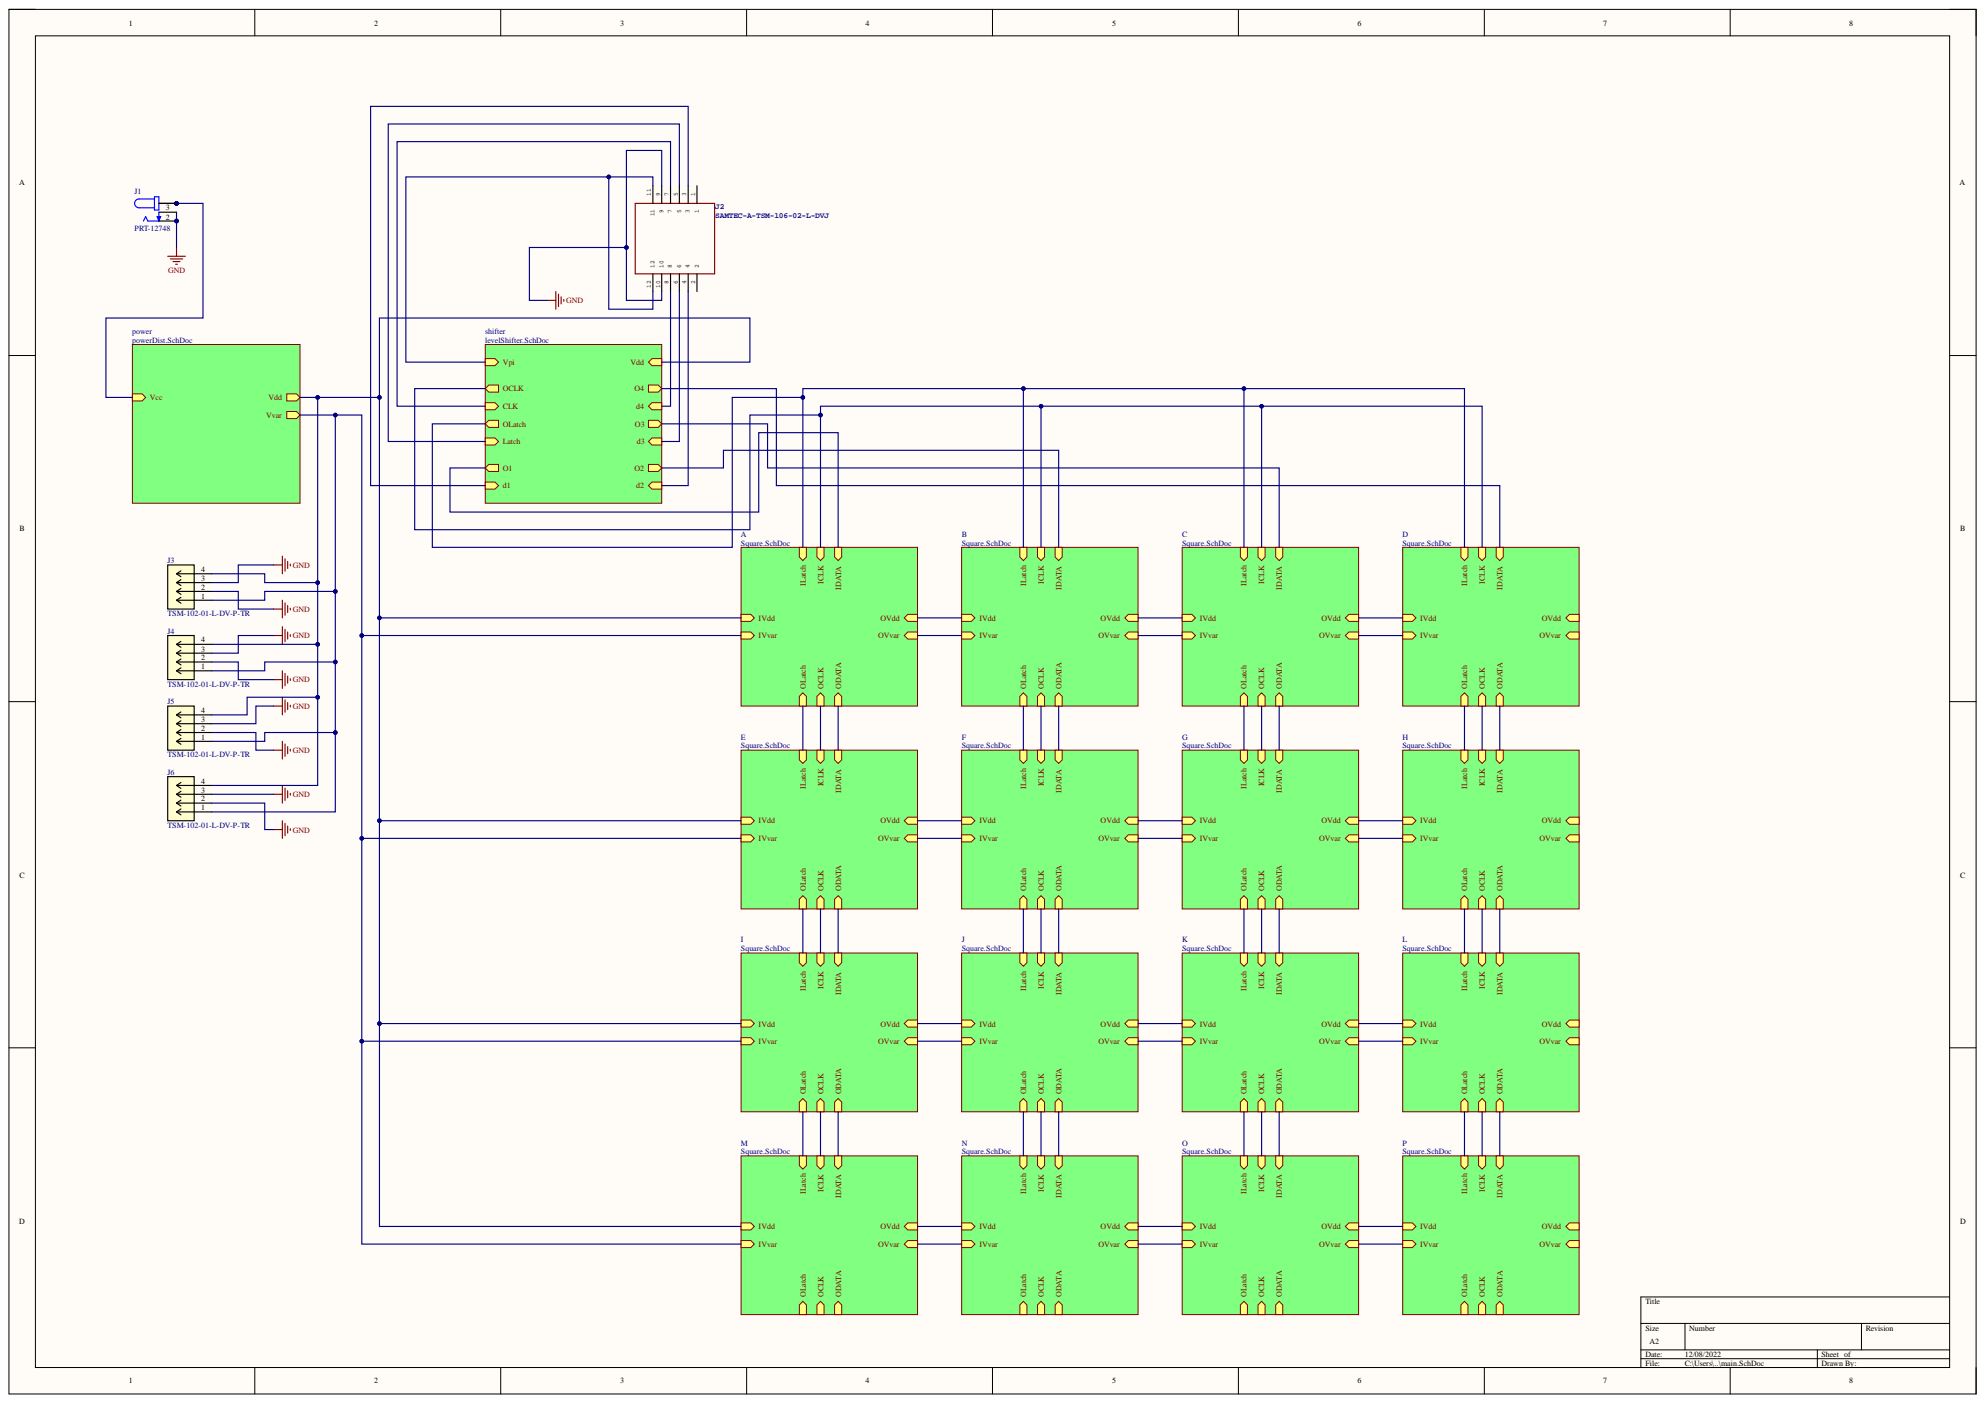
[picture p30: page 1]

CLK d4

Vvar | | OLatch O3

Latch d3 O1 O2 d1 d2

Square.SchDoc | B Square.SchDoc

IVdd OVdd IVvar OVvar | IVdd OVdd IVvar OVvar | IVdd OVdd IVvar OVvar | IVdd OVdd IVvar OVvar

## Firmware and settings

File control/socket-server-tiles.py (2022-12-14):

## Socket server to receive RIS configurations 
import socket
import csv
import tileif as tif

PORT = 13591

# Initialise GPIO pins of raspberry pi
tif.initPIcom()

# create TCP/IP socket
sock = socket.socket(socket.AF_INET, socket.SOCK_STREAM)

# retrieve local hostname
local_hostname = socket.gethostname()

# get fully qualified hostname
local_fqdn = socket.getfqdn()

# get the according IP address
ip_address = socket.gethostbyname(local_hostname)

ip_address = "192.168.4.1"

# output hostname, domain name and IP address
print ("working on %s (%s) with %s" % (local_hostname, local_fqdn, ip_address))

# bind the socket to the port 23456
server_address = (ip_address, PORT)
print('starting up on %s port %s' % server_address)
sock.bind(server_address)


# listen for incoming connections (server mode) with one connection at a time
sock.listen(1)

while True:
    # wait for a connection
    print('waiting for a connection')
    connection, client_address = sock.accept()
    try:
        # show who connected to us
        print('connection from', client_address)
        while True:
            sockdata = connection.recv(1025)
            if sockdata:
                if len(sockdata) == 1025:
                # output received data
                    stream = str(sockdata)
                    bitstring = stream[4:-1]
                    tilestring = stream[2:4]
                    tile_num = int(tilestring)
                # remove MATLAB matrix formatting
                    data = bitstring.replace(';',' ')
                    u = data.split()
                    g = [int(x) for x in u]
                    if len(g) < 512:
                        connection.sendall('b'.encode('utf-8'))
                        break	                
                    tif.setconf(tile_num, g) # Set configuration g on tile tile_num
                    connection.sendall('a'.encode('utf-8')) # Send acknowledgment of data reception
            else:
                # no more data -- quit the loop
                print("no more data.")
                break
    finally:
        # Clean up the connection
        connection.close()

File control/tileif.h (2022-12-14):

## Header file for interfacing with the OpenRIS tiles

import RPi.GPIO as GPIO

SCLK =  [3,11,21]
LATCH = [5,13,23]
DATA1 = [7,15,22]
DATA2 = [8,16,24]
DATA3 = [10,18,26]
DATA4 = [12,19,29]

## Mapping for HV5308 shift registers
map = [16,14,15,13,8,7,6,5,4,3,12,11,2,1,9,10,17, \
	18,25,26,19,20,27,28,29,30,32,31,22,24,23,21]
map.reverse()

colmap = map + [x + 32 for x in map] + [x + 64 for x in map] + [x + 96 for x in map]
colmap = [x - 1 for x in colmap]

# Initialise GPIO of Raspberry Pi
def initPIcom():
	GPIO.setmode(GPIO.BOARD)
	GPIO.setwarnings(False)
	for k in range(0,3):
		GPIO.setup(DATA1[k], GPIO.OUT)
		GPIO.setup(DATA2[k], GPIO.OUT)
		GPIO.setup(DATA3[k], GPIO.OUT)
		GPIO.setup(DATA4[k], GPIO.OUT)
		GPIO.setup(SCLK[k], GPIO.OUT)
		GPIO.setup(LATCH[k], GPIO.OUT)

# Rearrange order of bits to reflect correct order on the shift register output lines
def mapbits(bits):
	D1,D2,D3,D4 = [],[],[],[]
	for k in range(0,16):
		D1 = D1 + bits[(24 + k*32):(24 + k*32 + 8)]
		D2 = D2 + bits[(16 + k*32):(16 + k*32 + 8)]
		D3 = D3 + bits[( 8 + k*32):( 8 + k*32 + 8)]
		D4 = D4 + bits[(k*32):(k*32 + 8)]
	D1_mapped = [D1[i] for i in colmap]
	D2_mapped = [D2[i] for i in colmap]
	D3_mapped = [D3[i] for i in colmap]
	D4_mapped = [D4[i] for i in colmap]
	return D1_mapped, D2_mapped, D3_mapped, D4_mapped


# Input: tile number (1-3) and configuration (512 bits) for given tile
def setconf(tile_num, config):

	# Data for 4 columns of shift registers (128 bits per)
	D1,D2,D3,D4 = mapbits(config)

	# Tile number index (0-2)
	t = tile_num - 1

	# Set latch low
	GPIO.output(LATCH[t], GPIO.LOW)

	# Cycle over 4 parallel data streams
	for k in range(0,128):
		GPIO.output(SCLK[t], GPIO.LOW)
		## Send out data on 4 lines
		if D1[k] > 0:
			GPIO.output(DATA1[t], GPIO.HIGH)
		else:
			GPIO.output(DATA1[t], GPIO.LOW)
		if D2[k] > 0:
			GPIO.output(DATA2[t], GPIO.HIGH)
		else:
			GPIO.output(DATA2[t], GPIO.LOW)
		if D3[k] > 0:
			GPIO.output(DATA3[t], GPIO.HIGH)
		else:
			GPIO.output(DATA3[t], GPIO.LOW)
		if D4[k] > 0:
			GPIO.output(DATA4[t], GPIO.HIGH)
		else:
			GPIO.output(DATA4[t], GPIO.LOW)
		# Clock in the data lines
		GPIO.output(SCLK[t], GPIO.HIGH)
	# Latch in data
	GPIO.output(LATCH[t], GPIO.HIGH)

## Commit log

2022-12-07 Uploading data from ff measurements
    [1.csv, 10.csv, 11.csv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]
2022-12-08 Added hardware diagrams
    [OpenRIS_0v1.PrjPcb, Square.SchDoc, levelShifter.SchDoc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]
2023-03-26 Uploaded gerber files
2023-03-26 Added Gerber files
2023-03-26 Uploaded drill file
2023-03-26 Uploaded BoM and stackup
    [openris_bom_v1p0.xlsx]
2023-10-02 Updated drill files
